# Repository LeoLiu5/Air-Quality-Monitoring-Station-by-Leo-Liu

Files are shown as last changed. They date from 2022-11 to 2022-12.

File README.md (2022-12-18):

# CASA0016-Air Quality Monitoring Station by Leo Liu 

> ## Project Objective 
> <br> The purpose of this project is to provide a worked-out example of how to build an indoor air quality monitoring system (temperature, humidity, pm2.5, TVOC, and its equivalent carbon dioxide (eCO2) values). The initial deployment will be in the Connected Environments Lab in One Pool Street. It would be worthwhile to examine the air quality in the lab since CE staff and students are having regular meetings in this newly furnished room.

><br>

## - Main Hardware Components

- ### [Arduino MKR WiFi 1010](https://thepihut.com/products/arduino-mkr-wifi-1011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) is used as the microcontroller board for this project. It can be connected through Wi-Fi communication and is smaller in size.

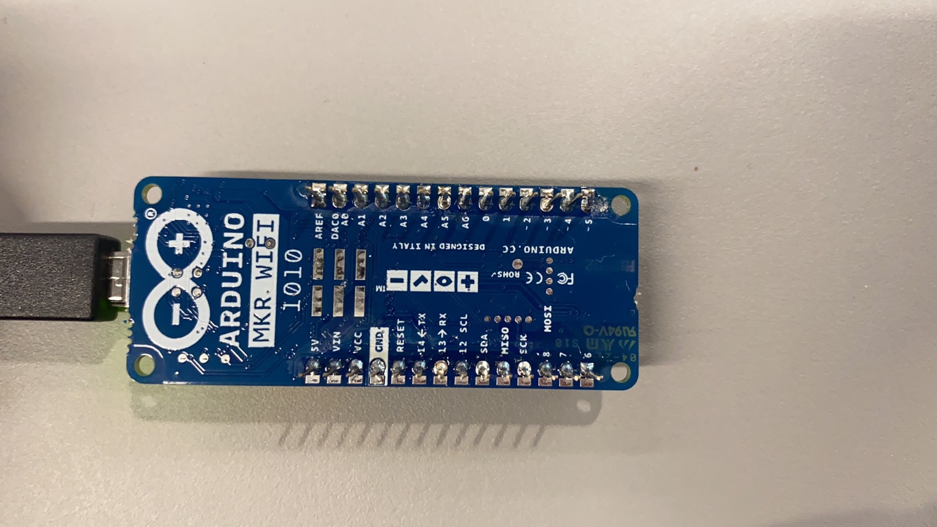
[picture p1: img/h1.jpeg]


- ### [A PMS5003 particulate matter sensor with cable](https://coolcomponents.co.uk/products/pm2-5-air-quality-sensor-and-breadboard-adapter-kit-pms5003) is used to sense particulates of various sizes (PM1, PM2.5, PM10) from sources like smoke, dust, pollen, metal and organic particles.

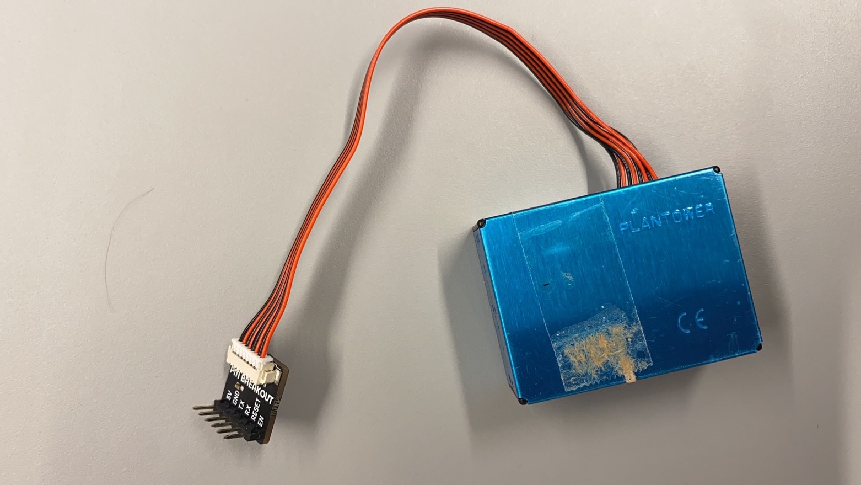
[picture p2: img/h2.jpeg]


- ### [A DHT22 temperature/humidity sensor](https://thepihut.com/products/dht22-temperature-humidity-sensor-extras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), which returns temperature and humidity readings.

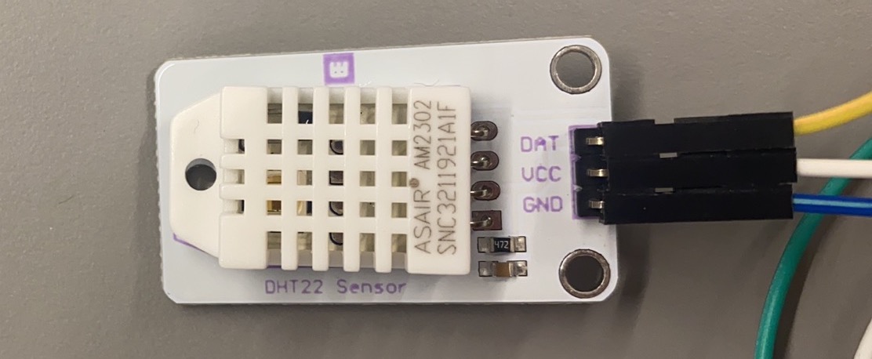
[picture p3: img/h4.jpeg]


- ### [An Adafruit SGP30 TVOC/eCO2 Gas Sensor](https://learn.adafruit.com/adafruit-sgp30-gas-tvoc-eco2-mox-sensor), is used to calculate total volatile organic compounds (TVOC) and its equivalent carbon dioxide (eCO2) values. This sensor detects Volatile Organic Compounds (VOCs) and H2 for indoor air quality monitoring.
> <br> TVOC includes pollutants from static sources and variable sources (Holøs et al., 2018). Construction materials, fittings, equipment and surface treatments belong to static sources. Residents or resident-related activities such as using cleaning compounds or bringing in new objects are variable sources. Both sources have the highest impacts at the start of a building’s service life. Therefore, the concentration of TVOC in a newly furnished building follows a multi-exponential decay trend over time after the construction is complete (Holøs et al., 2018). 

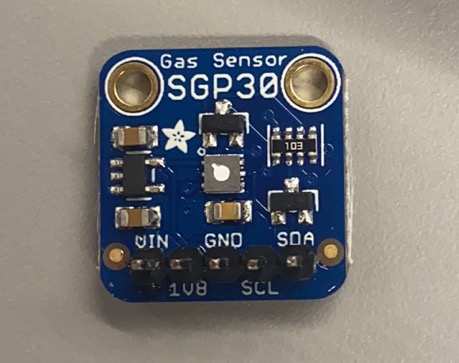
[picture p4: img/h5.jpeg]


- ### [An I2C 16x2 LCD Display](https://thepihut.com/products/i2c-16x2-arduino-lcd-display-module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) is used to display the live sensor data locally as an integral part of the system. The Arduino-compatible LCD screen is ideal for displaying text, numbers, and special characters of the live data. 

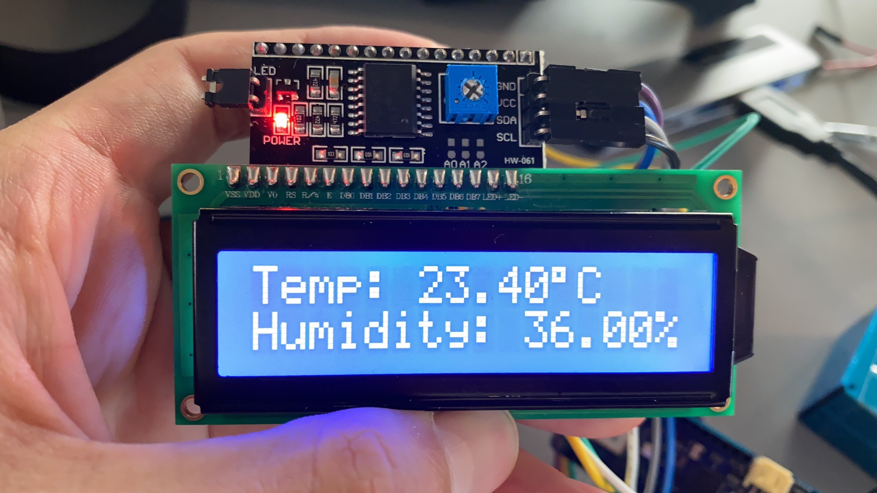
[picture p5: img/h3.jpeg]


## - First Prototype: Components Assemblage 



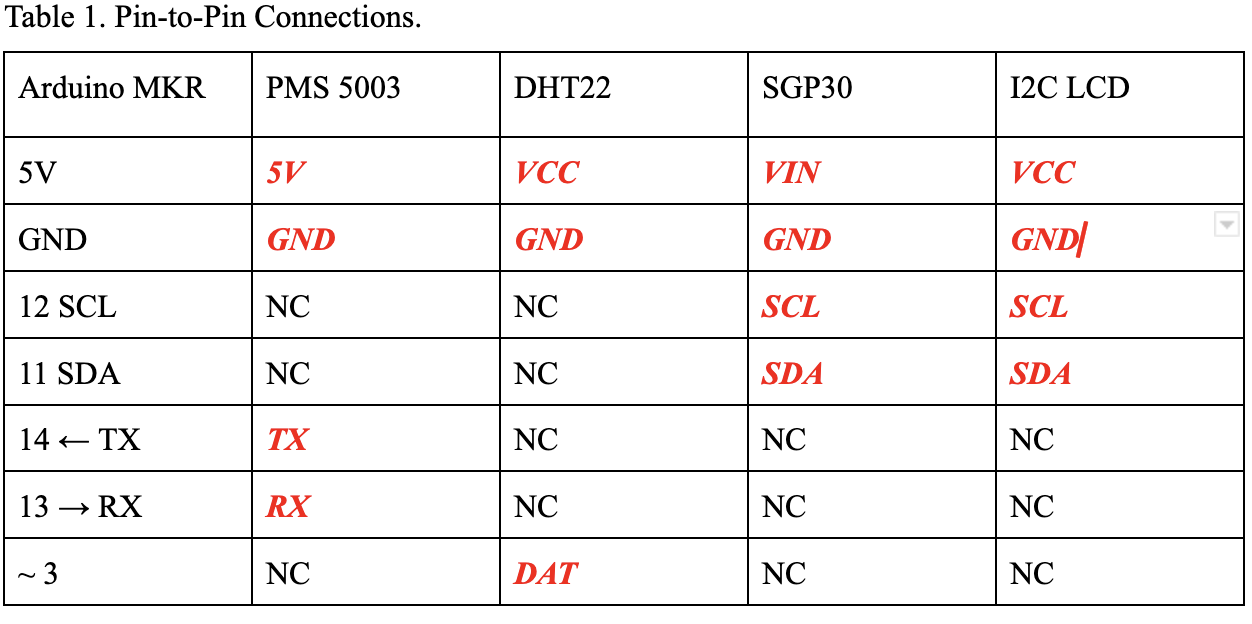
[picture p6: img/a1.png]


- A serial data communication employing an I2C (Inter-Integrated Circuit) master/slave bus controller is implemented for SGP30 and the I2C LCD. 
- Unlike traditional data transfer bus systems (USB, SPI, Microwire, and UARTS), I2C requires only two wires (SDA and SCL) to transmit information between devices connected to the bus (Kaneriya & Jagtap, 2015).

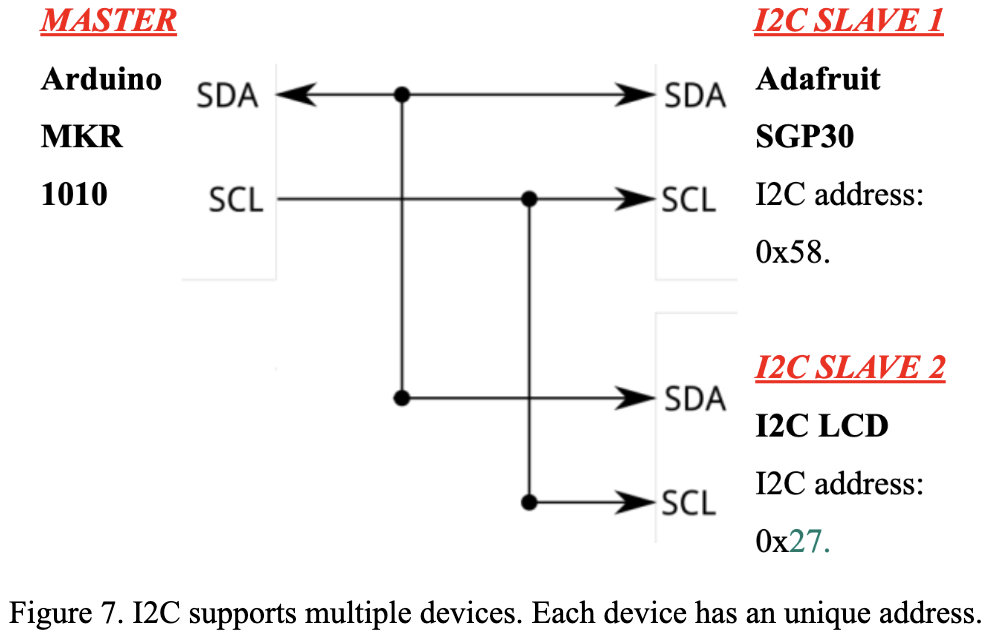
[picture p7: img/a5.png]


- The hardware components are connected to Arduino MKR through jumping wires.

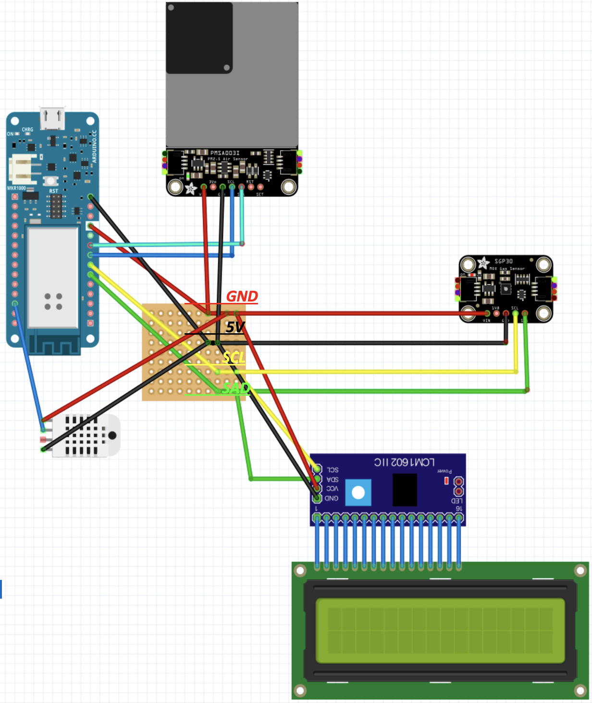
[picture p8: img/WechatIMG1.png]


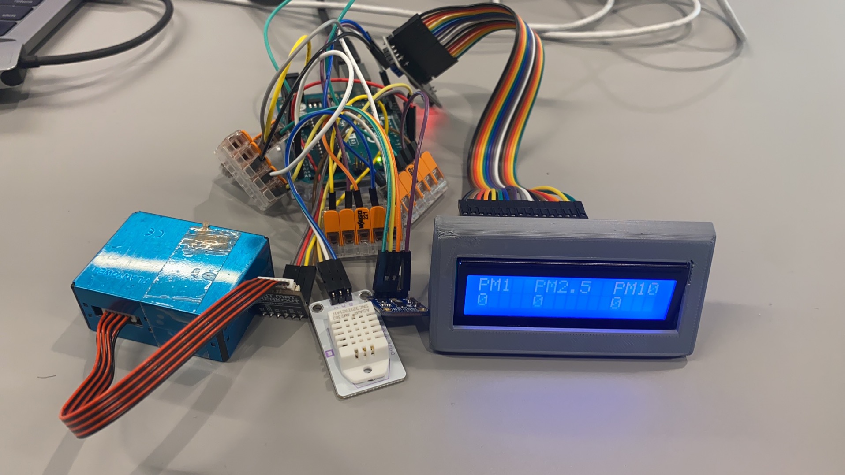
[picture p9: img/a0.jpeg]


Interior design:
- Compactness and tidiness
- Clearness and simplicity 

- Wago Lever Connectors ---> A Copper Stripboard 
- Each row on the copper stripboard is designed for a specific pin.

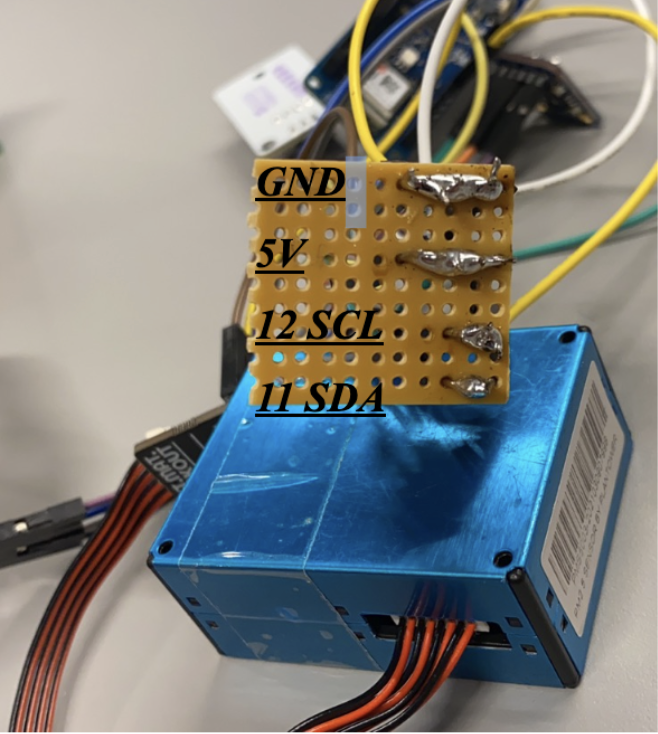
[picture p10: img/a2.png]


- Jumping Wires --> Heat-Shrink Tubing
- To organize the wires and make everything tidy.

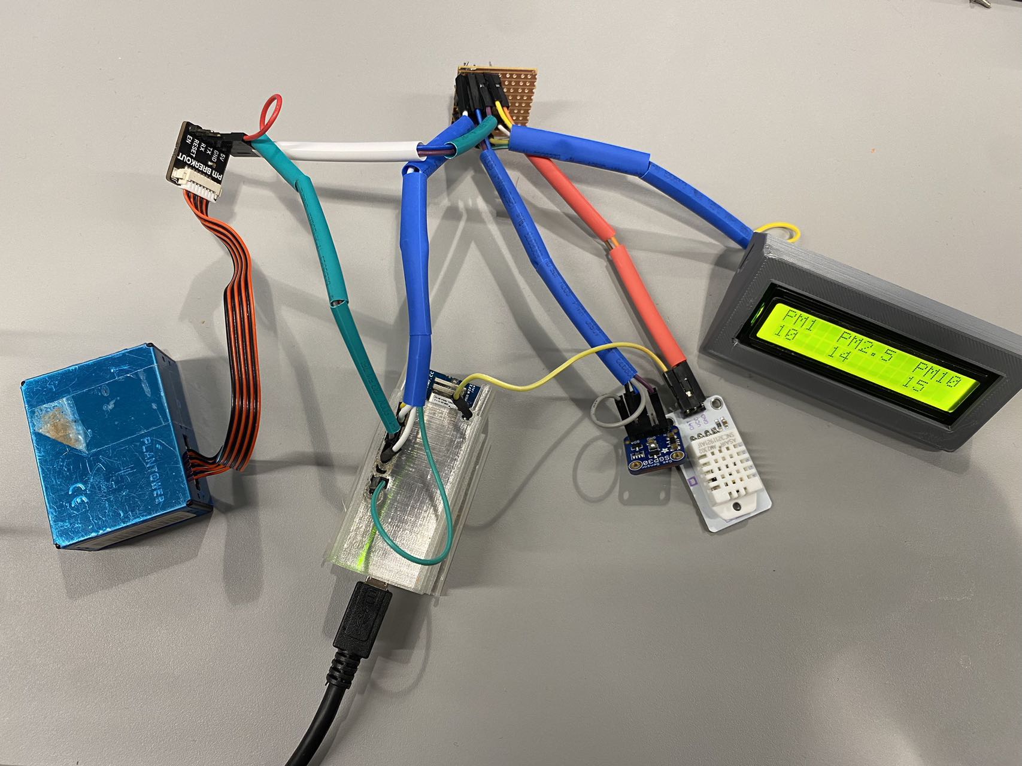
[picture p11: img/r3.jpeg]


- The plastic protector from the previous plant monitor assessment is used to protect and hold the board.

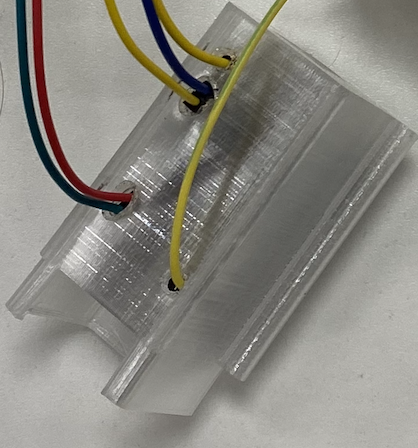
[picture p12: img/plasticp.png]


## - Second Prototype: deploy the device as it stands
- Choose and deploy suitable enclosures --> 3D Printed Enclosure

Exterior design:
- Holes --> Air Flow
- Screws --> Maintenance issues 

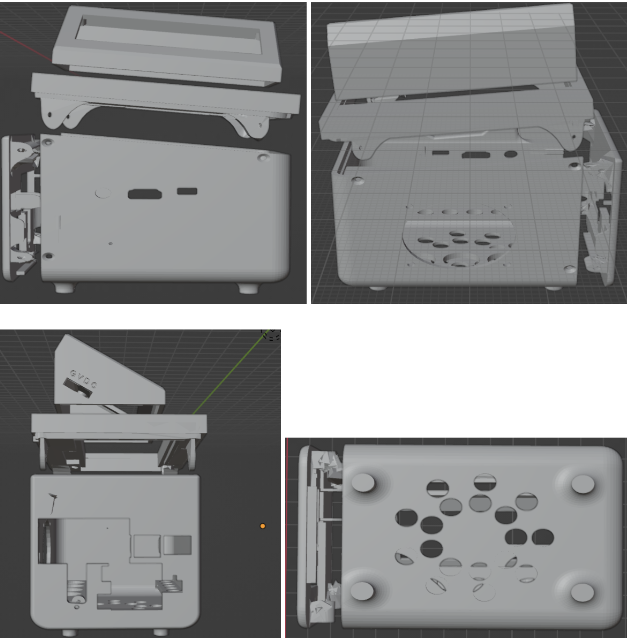
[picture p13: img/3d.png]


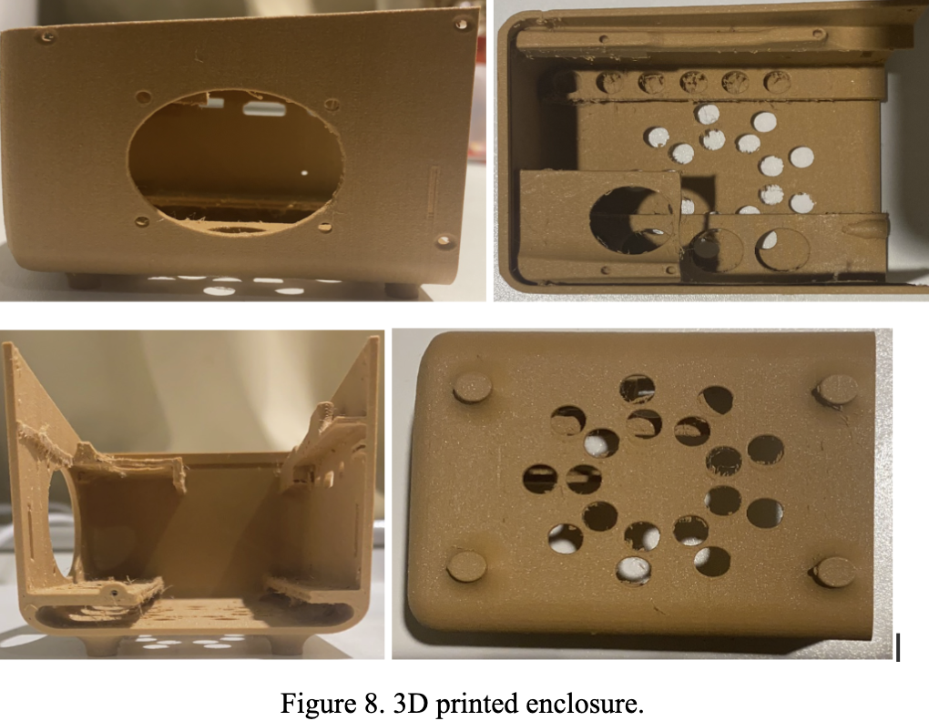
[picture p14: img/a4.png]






Interior design:
- Compactness and tidiness
- Clearness and simplicity 

- 1 cm above the bottom of the enclosure, a thin broken layer is produced for sliding in the plastic protector and the stripe board, to fix their positions and prevent wobbliness. 

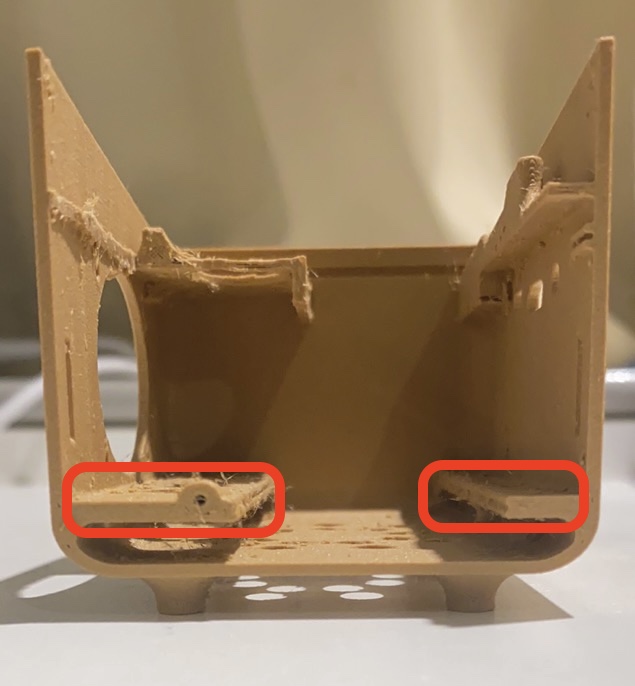
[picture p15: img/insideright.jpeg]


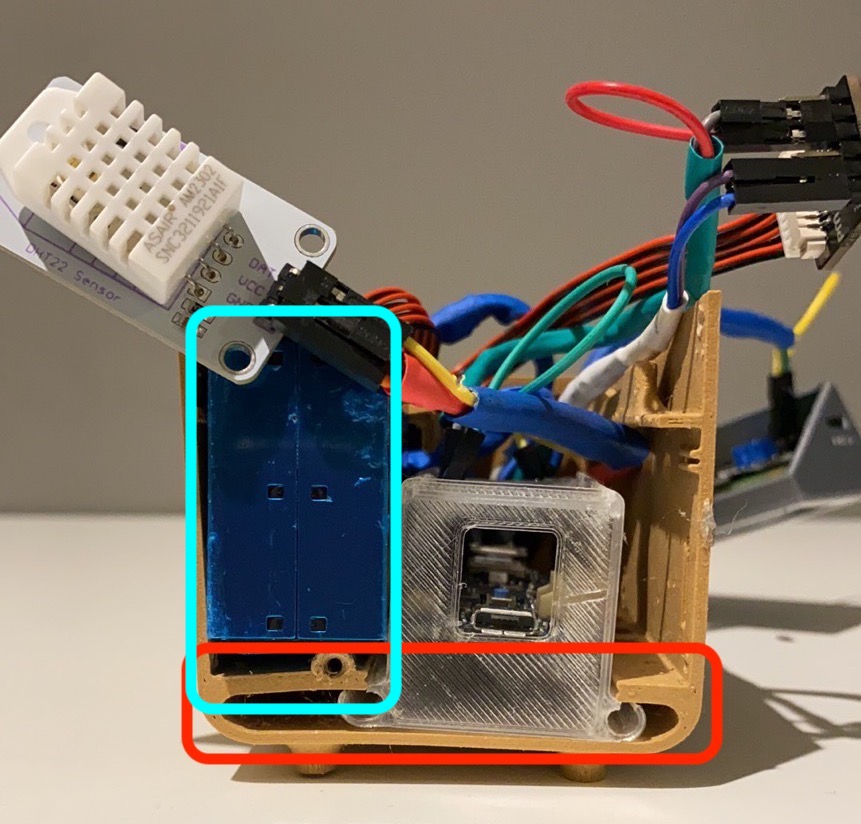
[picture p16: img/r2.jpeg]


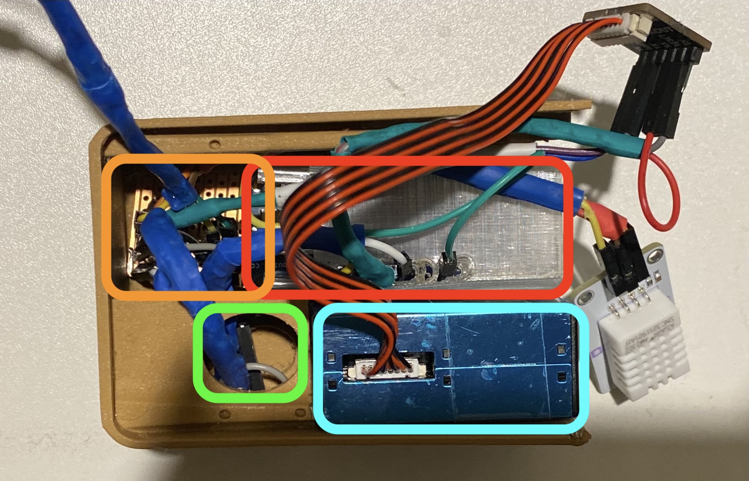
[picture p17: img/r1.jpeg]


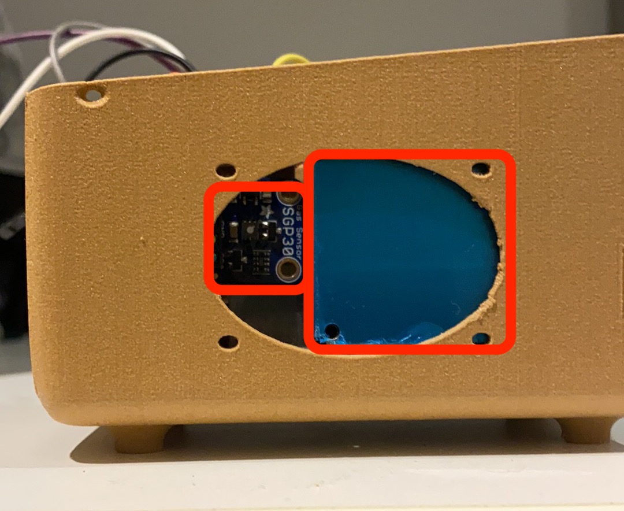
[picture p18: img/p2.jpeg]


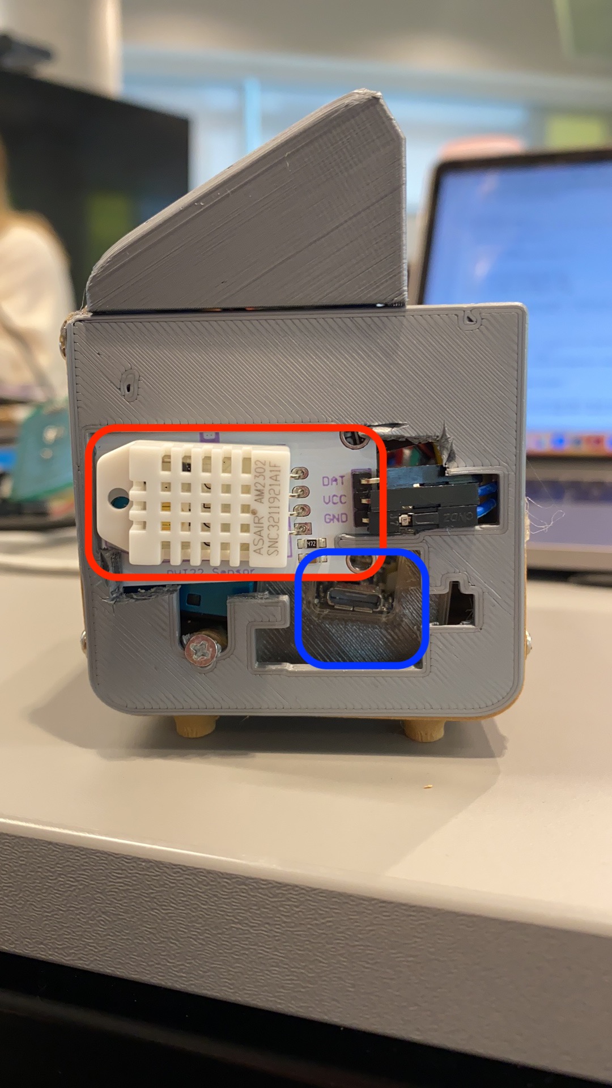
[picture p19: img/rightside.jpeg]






Flushing as much fresh air through the building as possible is the best way to clear out toxic Volatile Organic Compounds (VOCs). Such as temporarily increasing the ventilation rate or the fresh air change rate to counter the high pollutant-load from off-gassing of volatile compounds from new materials in the building.

## - References
><br>
- Ada, L. (no date) Adafruit SGP30 TVOC/Eco2 Gas Sensor, Adafruit Learning System. Available at: https://learn.adafruit.com/adafruit-sgp30-gas-tvoc-eco2-mox-sensor/arduino-code (Accessed: December 14, 2022). 

- Ada, L. (no date) PM2.5 Air Quality Sensor, Adafruit Learning System. Available at: https://learn.adafruit.com/pm25-air-quality-sensor?view=all (Accessed: December 14, 2022). 

- Holøs, S.B. et al. (2018) “VOC emission rates in newly built and renovated buildings, and the influence of ventilation – a review and meta-analysis,” International Journal of Ventilation, 18(3), pp. 153–166. Available at: https://doi.org/10.1080/14733315.2018.1435026. 

- Kaneriya, H. and Jagtap, S. (2015) “Design Of I2C Master With Multiple Slave”, International Journal on Recent and Innovation Trends in Computing and Communication, 3(5), pp. 2890–2893. Available at: https://doi.org/10.17762/ijritcc.v3i5.4356.
><br>

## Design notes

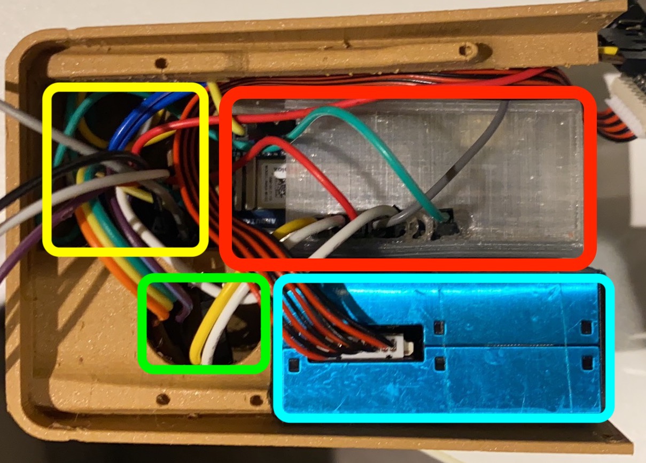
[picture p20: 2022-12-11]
img/a3copy.jpeg

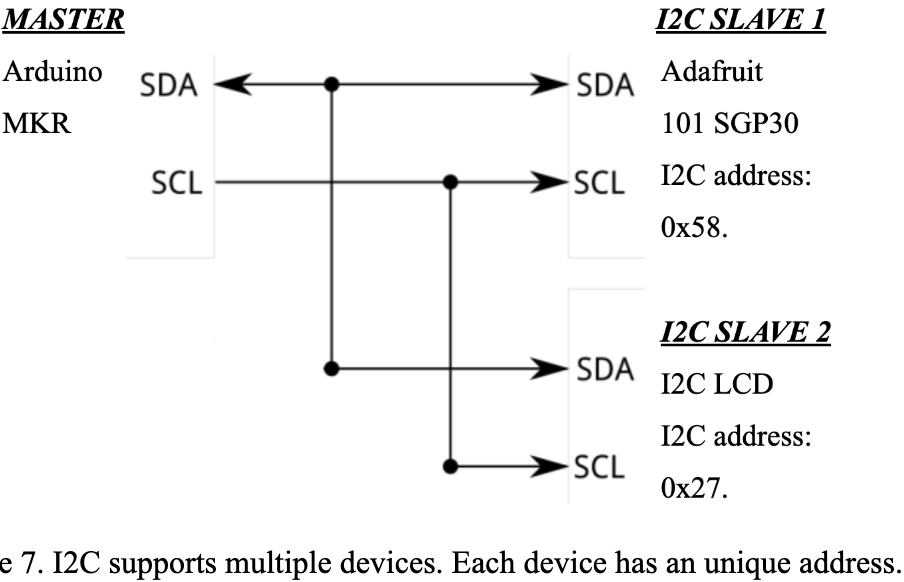
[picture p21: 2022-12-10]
img/a3.png

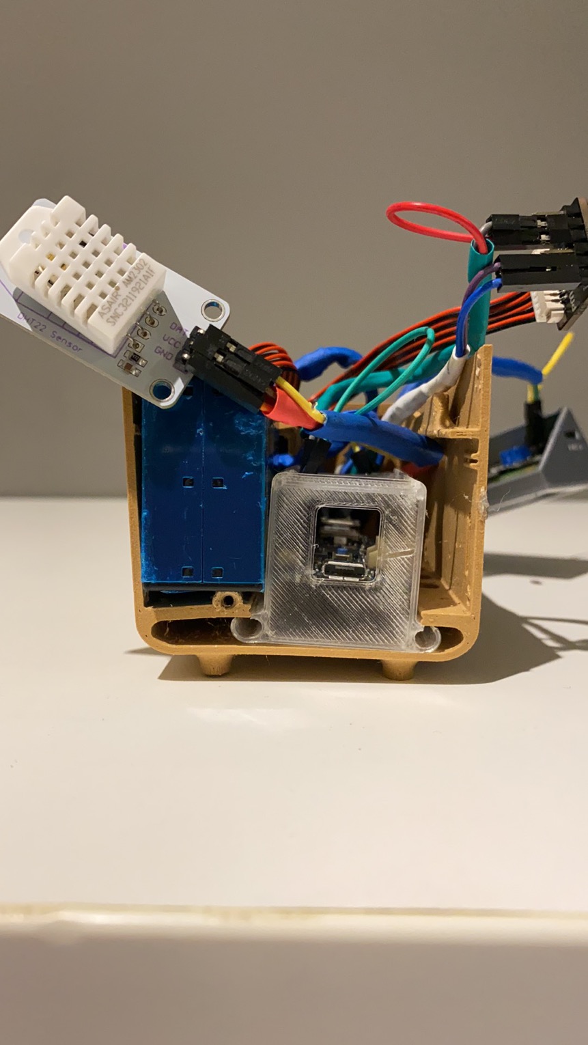
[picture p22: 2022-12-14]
img/WechatIMG92.jpeg

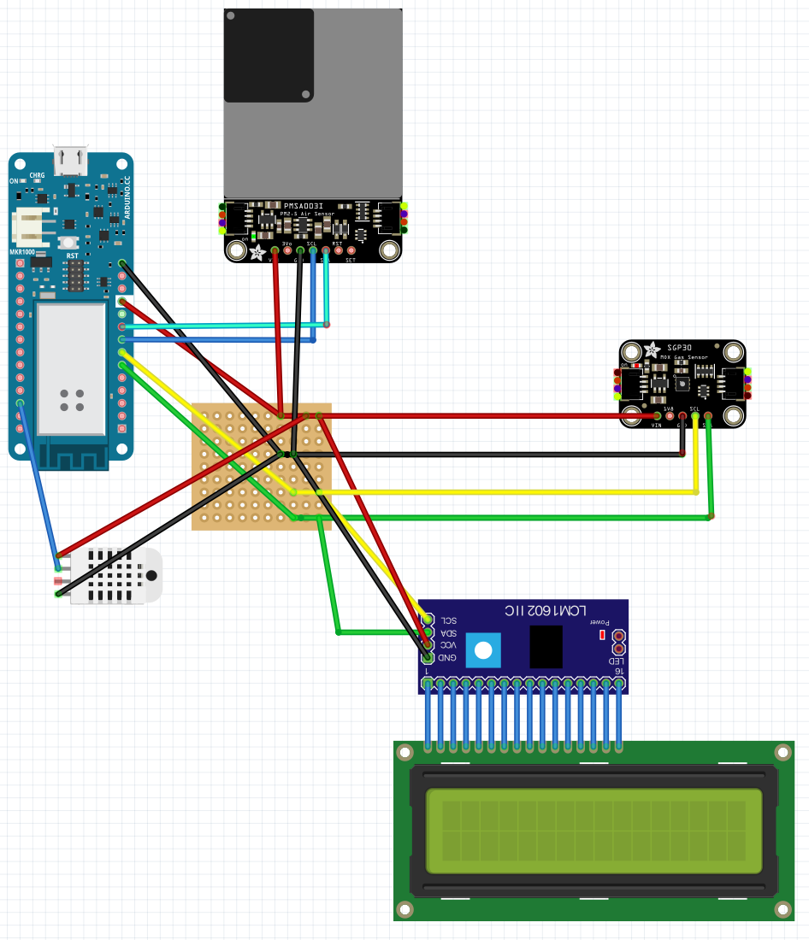
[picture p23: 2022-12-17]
img/circ.png

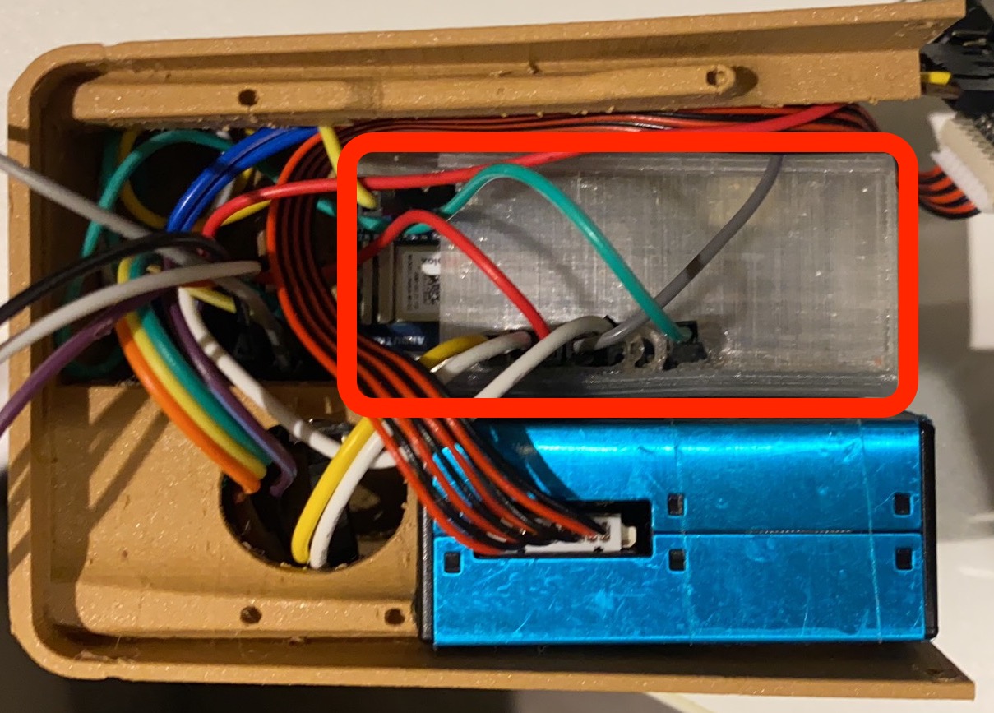
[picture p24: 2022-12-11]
img/a3.jpeg

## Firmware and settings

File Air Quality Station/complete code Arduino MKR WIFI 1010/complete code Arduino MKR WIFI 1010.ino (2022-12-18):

/* Test sketch for sensors */
//Libraries
#include "Adafruit_PM25AQI.h"
#include "Adafruit_SGP30.h"
#include <DHT.h>;
#include <LiquidCrystal_I2C.h>
// #include "PMS.h"              // https://github.com/fu-hsi/pms
// comment these two lines if using hardware serial
// #include <SoftwareSerial.h>
// SoftwareSerial pmSerial(2, 3);
// #include <Wire.h>
// PMS pms(Serial1);

// Sensor variables are declared:

Adafruit_PM25AQI aqi = Adafruit_PM25AQI();  //Setting up PMS5003 data
Adafruit_SGP30 sgp;                         //Setting up SGP30 data

#define DHTPIN 3           // what pin we're connected to
#define DHTTYPE DHT22      // DHT 22  (AM2302)
DHT dht(DHTPIN, DHTTYPE);  //// Initialize DHT sensor for normal 16mhz Arduino
//Constants
float hum;   //Stores humidity value
float temp;  //Stores temperature value

int totalColumns = 16;
int totalRows = 2;
//I2C pins declaration for 1602A with I2C module
LiquidCrystal_I2C lcd(0x27, totalColumns, totalRows);

void setup() {
  // Wait for serial monitor to open
  Serial.begin(115200);
  while (!Serial) delay(10);
  Serial.println("SGP30 test");

  if (!sgp.begin()) {
    Serial.println("Sensor not found :(");
    while (1)
      ;
  }
  Serial.print("Found SGP30 serial #");
  Serial.print(sgp.serialnumber[0], HEX);
  Serial.print(sgp.serialnumber[1], HEX);
  Serial.println(sgp.serialnumber[2], HEX);
  // If you have a baseline measurement from before you can assign it to start, to 'self-calibrate'
  // sgp.setIAQBaseline(0x8E68, 0x8F4E);  // Will vary for each sensor!
  Serial.println(" PMS5003 Air Quality Sensor");

  // Wait 20 seconds for sensor to boot up!
  delay(20000);

  // If using serial, initialize it and set baudrate before starting!
  // Uncomment one of the following
  Serial1.begin(9600);
  // pmSerial.begin(9600);
  // There are 3 options for connectivity!
  // if (! aqi.begin_I2C()) {      // connect to the sensor over I2C
  if (! aqi.begin_UART(&Serial1)) {  // connect to the sensor over hardware serial
  // if (! aqi.begin_UART(&pmSerial)) { // connect to the sensor over software serial
  Serial.println("Could not find PM 2.5 sensor!");
  while (1) delay(10);
  }

  Serial.println("PM25 found!");
  dht.begin();
  lcd.init();

  lcd.backlight();  // use to turn on and turn off LCD back light
}

int counter = 0;

void loop() {
  // PMS::DATA data;
  PM25_AQI_Data data;
  if (!aqi.read(&data)) {
    Serial.println("Could not read from AQI");
    delay(1000);  // try again in a bit!
    return;
  }

  Serial.println("AQI reading success");

  Serial.println(F("Concentration Units (standard)"));
  Serial.println(F("---------------------------------------"));
  Serial.print(F("PM 1.0: "));
  Serial.print(data.pm10_standard);
  Serial.print(F("\t\tPM 2.5: "));
  Serial.print(data.pm25_standard);
  Serial.print(F("\t\tPM 10: "));
  Serial.println(data.pm100_standard);
  Serial.println(F("Concentration Units (environmental)"));
  Serial.println(F("---------------------------------------"));
  Serial.print(F("PM 1.0: "));
  Serial.print(data.pm10_env);
  Serial.print(F("\t\tPM 2.5: "));
  Serial.print(data.pm25_env);
  Serial.print(F("\t\tPM 10: "));
  Serial.println(data.pm100_env);
  Serial.println(F("---------------------------------------"));
  Serial.print(F("Particles > 0.3um / 0.1L air:"));
  Serial.println(data.particles_03um);
  Serial.print(F("Particles > 0.5um / 0.1L air:"));
  Serial.println(data.particles_05um);
  Serial.print(F("Particles > 1.0um / 0.1L air:"));
  Serial.println(data.particles_10um);
  Serial.print(F("Particles > 2.5um / 0.1L air:"));
  Serial.println(data.particles_25um);
  Serial.print(F("Particles > 5.0um / 0.1L air:"));
  Serial.println(data.particles_50um);
  Serial.print(F("Particles > 10 um / 0.1L air:"));
  Serial.println(data.particles_100um);
  Serial.println(F("---------------------------------------"));
  Serial.println(F("---------------------------------------"));
  //Read data and store it to variables hum and temp
  hum = dht.readHumidity();
  temp = dht.readTemperature();
  //Print temp and humidity values to serial monitor
  Serial.print("Humidity: ");
  Serial.print(hum);
  Serial.print(" %, Temp: ");
  Serial.print(temp);
  Serial.println(" Celsius");
  if (!sgp.IAQmeasure()) {
    Serial.println("Measurement failed");
    return;
  }
  Serial.print("TVOC ");
  Serial.print(sgp.TVOC);
  Serial.print(" ppb\t");
  Serial.print("eCO2 ");
  Serial.print(sgp.eCO2);
  Serial.println(" ppm");

  if (!sgp.IAQmeasureRaw()) {
    Serial.println("Raw Measurement failed");
    return;
  }
  Serial.print("Raw H2 ");
  Serial.print(sgp.rawH2);
  Serial.print(" \t");
  Serial.print("Raw Ethanol ");
  Serial.print(sgp.rawEthanol);
  Serial.println("");
  delay(1000);

  counter++;
  if (counter == 30) {
    counter = 0;

    uint16_t TVOC_base, eCO2_base;
    sgp.getIAQBaseline(&eCO2_base, &TVOC_base);
    if (!sgp.getIAQBaseline(&eCO2_base, &TVOC_base)) {
      Serial.println("Failed to get baseline readings");
      return;
    }
    Serial.print("****Baseline values: eCO2: 0x");
    Serial.print(eCO2_base, HEX);
    Serial.print(" & TVOC: 0x");
    Serial.println(TVOC_base, HEX);
  }

  // Converting the sensor readings to string values that the LCD can display
  String pm1String = String(data.pm10_env);
  String pm25String = String(data.pm25_env);
  String pm100String = String(data.pm100_env);
  String tempString = String(temp);
  String humString = String(hum);
  String TVOCString = String(sgp.TVOC);
  String eCO2String = String(sgp.eCO2);

  unsigned long previousMillis = 0;
  unsigned long interval = 1000;  //Refreshes the LCD once every 1000ms (1 seconds)

  unsigned long currentMillis = millis();
  if (currentMillis - previousMillis > interval) {
    previousMillis = currentMillis;

    lcd.clear();  //Clear the screen
    lcd.setCursor(0, 0);
    lcd.print("PM1  PM2.5  PM10");
    lcd.setCursor(0, 1);
    lcd.print(pm1String);
    lcd.setCursor(5, 1);
    lcd.print(pm25String);
    lcd.setCursor(12, 1);
    lcd.print(pm100String);
    delay(10000);

    lcd.clear();  //Clear the screen
    lcd.setCursor(0, 0);
    lcd.print("Temp:");
    lcd.setCursor(6, 0);
    lcd.print(tempString);
    lcd.setCursor(11, 0);
    lcd.print((char)223);
    lcd.setCursor(12, 0);
    lcd.print("C");
    lcd.setCursor(0, 1);
    lcd.print("Humidity:");
    lcd.setCursor(10, 1);
    lcd.print(humString);
    lcd.setCursor(15, 1);
    lcd.print("%");
    delay(10000);

    lcd.clear();  //Clear the screen
    lcd.setCursor(0, 0);
    lcd.print("TVOC:");
    lcd.setCursor(6, 0);
    lcd.print(TVOCString);
    lcd.setCursor(13, 0);
    lcd.print("ppb");
    lcd.setCursor(0, 1);
    lcd.print("eco2:");
    lcd.setCursor(6, 1);
    lcd.print(eCO2String);
    lcd.setCursor(13, 1);
    lcd.print("ppm");
    delay(10000);
  }
}

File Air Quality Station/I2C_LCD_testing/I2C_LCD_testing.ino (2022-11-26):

#include <LiquidCrystal_I2C.h>
#include <Wire.h> 
int totalColumns = 16;
int totalRows = 2;

LiquidCrystal_I2C lcd(0x27, totalColumns, totalRows);

void setup(){
lcd.init(); 
lcd.backlight(); // use to turn on and turn off LCD back light
}

void loop()
{
lcd.setCursor(0, 0);
lcd.print("Microcontrollers");
lcd.setCursor(0,1);
lcd.print("I2C LCD tutorial");
delay(1000);
lcd.clear(); 
lcd.setCursor(0, 0);
lcd.print("Static text");
delay(1000);
lcd.setCursor(0,1);
lcd.print("I2C LCD tutorial");
delay(1000);
lcd.clear(); 
}

// //sketch created by Akshay Joseph

// #include <LiquidCrystal_I2C.h>

// LiquidCrystal_I2C lcd(0x27, 16, 2);

// void setup()
// {

// 	lcd.begin(16,2);


// 	lcd.backlight();
// 	lcd.clear();
// 	lcd.setCursor(4,0);
// 	lcd.print("Hackster");
// }

// void loop()
// {
// }

// #include <Wire.h>
// #include <hd44780.h>                       // main hd44780 header
// #include <hd44780ioClass/hd44780_I2Cexp.h> // i2c expander i/o class header

// hd44780_I2Cexp lcd;


// const int LCD_COLS = 16;
// const int LCD_ROWS = 2;

// void setup()
// {
// int status;


// 	status = lcd.begin(LCD_COLS, LCD_ROWS);
// 	if(status) // non zero status means it was unsuccesful
// 	{
// 		hd44780::fatalError(status); // does not return
// 	}
 
// 	lcd.print("Hello, World!");
// }

// void loop() {}

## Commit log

2022-11-28 add calibration
2022-12-17 circuit diagram
    [Circuit Diagram.fzz]
